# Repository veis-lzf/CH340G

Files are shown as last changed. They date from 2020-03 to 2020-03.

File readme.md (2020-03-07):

# CH340G下载器说明

- 如果需要使用免冷启动下载功能，在第一次使用时，需要用普通USB转TLL下载器给CH340G板上的STC15F104W下载固件（./Firmware/MDK5/Objects/CH340G-DL.hex）

	CH340G

- 烧录步骤说明：

	```
	1.连线： 
			USB转TTL下载器          CH340G自动下载器
	              TXD------------------->RX
	              RXD------------------->TX
	              
	2.给USB转TTL下载器上电，打开STC-ISP烧录工具;
	
	3.选择单片机型号为STC15F104W，选择COM口号，最低波特率为2400，程序运行频率为11.0592MHz；
	
	4.装载固件（/Firmware/MDK5/Objects/CH340G-DL.hex）；
	
	5.点击下载，给CH340G自动下载器上电（插上USB）；
	
	6.等待下载完毕，拔掉连线，完成。
	
	注：若烧写不成功，拔出CH340G自动下载器的USB，重复步骤5。
	```

- 若需要CH340G自动下载器给目标板供电，建议板载的三极管Q1更换为与s8550引脚兼容的大电流PNP管，如ss8550；如果不需要供电，则不需要焊接三极管Q1。

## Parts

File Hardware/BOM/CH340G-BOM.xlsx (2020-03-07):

Item | Reference | Value | PCB Footprint | Quantity
1 | C1 | 0.01uF | C0603 | 1
2 | C2 | 0.1uF | C0603 | 1
3 | C3 | 10uF | TA3216 | 1
4 | C4、C5 | 22pF | C0603 | 2
5 | C6 | 22uF | TA3216 | 1
6 | C7 | 0.1uF/NC | C0603 | 1
7 | D1 | 1N5819 | SOD123 | 1
8 | D2 | RED LED | LED0603 | 1
9 | D3 | YELLOW LED | LED0603 | 1
10 | D4 | GREEN LED | LED0603 | 1
11 | F1 | 1A | FULSE0805 | 1
12 | J1 | SMT-CON-4P-1R25 | 1_25_PWT_4P | 1
13 | J2 | CON4 | SIP-4 | 1
14 | J3 | CON2 | SIP-2 | 1
15 | Q1 | S8550 | SOT-23 | 1
16 | R1 | 300R | R0603 | 1
17 | R2、R3、R4、R5 | 1k | R0603 | 4
18 | USB1 | USB_A | USB-A-M-DIP | 1
19 | U1 | CH340G | SOIC-16 | 1
20 | U2 | STC15F104W | SOIC-8 | 1
21 | Y1 | 12MHz | HC-49S | 1

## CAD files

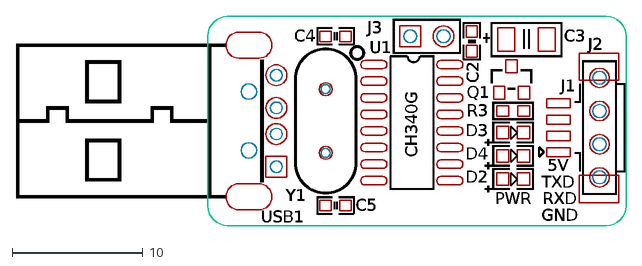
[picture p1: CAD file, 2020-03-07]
Hardware/PCB/Output/CH340G-PCB_TOP.dxf
J3
USB1
Y1
R3
D3
D4
D2
C2
C4
C5
C3
Q1
J2
J1
U1
PWR
CH340G
GND
TXD
RXD
5V

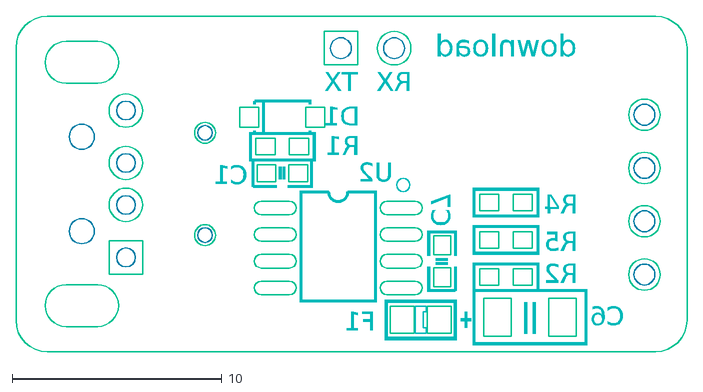
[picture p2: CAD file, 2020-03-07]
Hardware/PCB/Output/CH340G-PCB_BOTTOM.dxf
F1
R5
R4
R2
R1
C1
C7
D1
C6
U2
download
RX
TX

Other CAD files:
Firmware/MDK5/Objects/main.obj
Firmware/MDK5/Objects/STARTUP.obj

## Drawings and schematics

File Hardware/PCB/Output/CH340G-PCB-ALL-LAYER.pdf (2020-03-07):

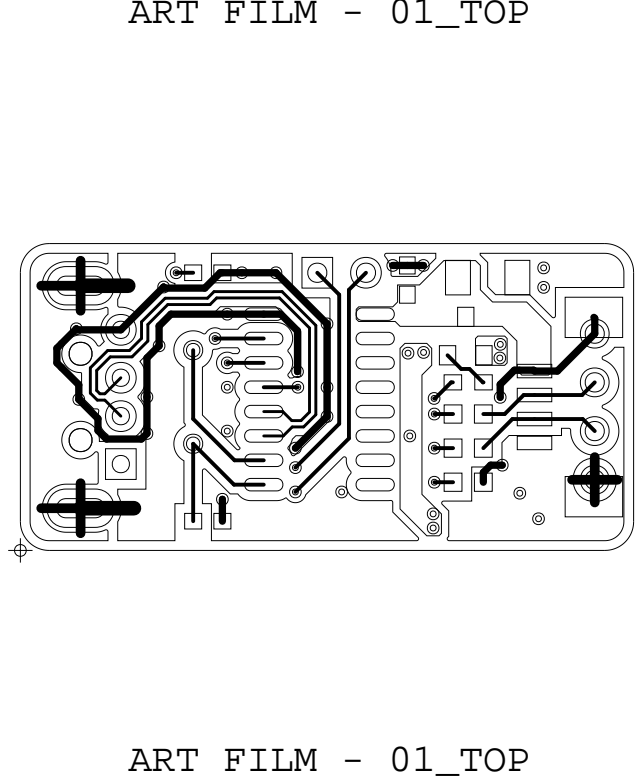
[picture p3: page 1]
ART FILM - 01_TOP

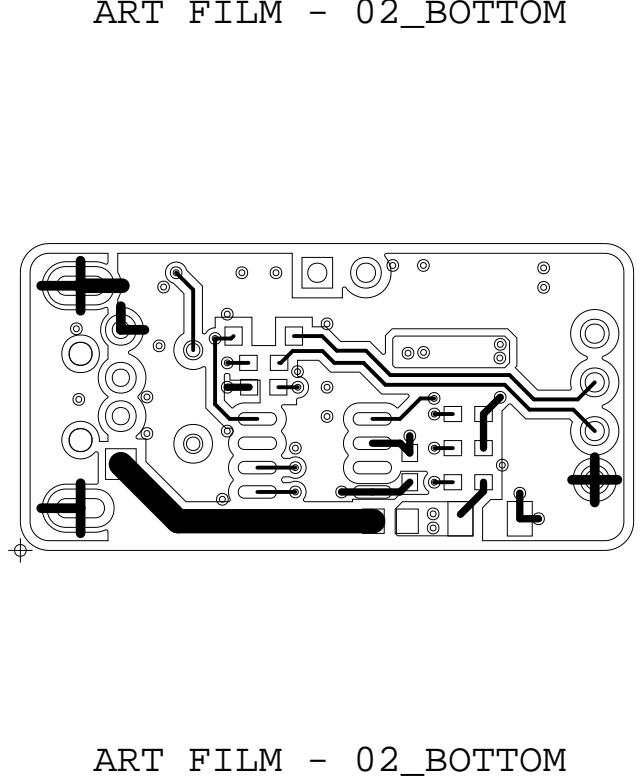
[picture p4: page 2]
ART FILM - 02_BOTTOM

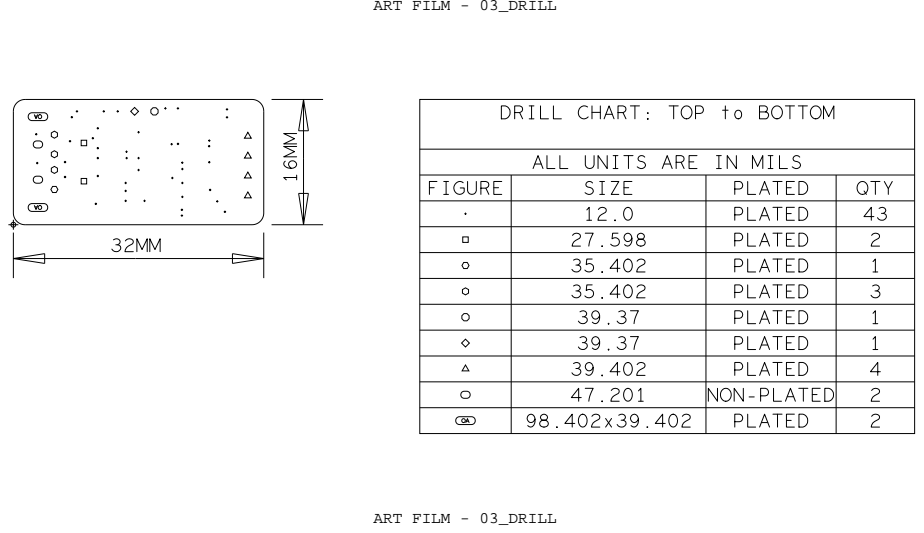
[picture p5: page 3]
ART FILM - 03_DRILL; QTY; PLATED; NON-PLATED; SIZE; ALL UNITS ARE IN MILS; DRILL CHART: TOP; to BOTTOM; FIGURE

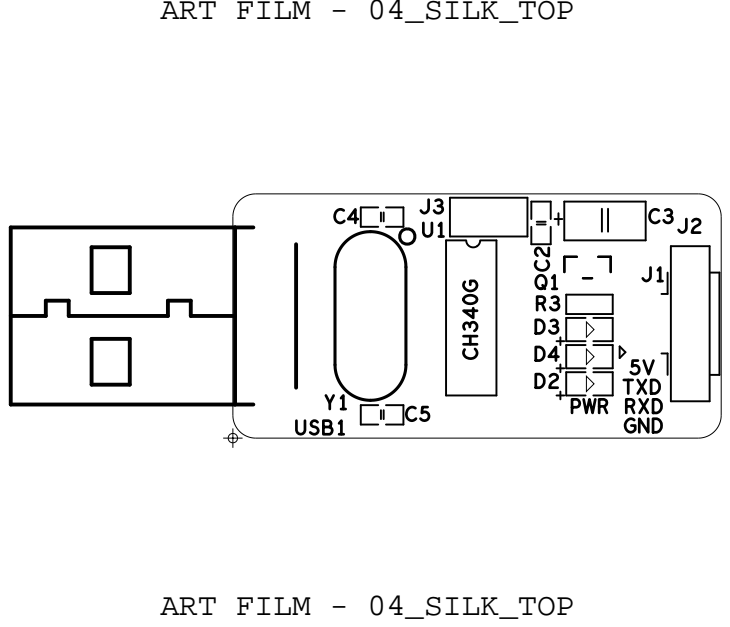
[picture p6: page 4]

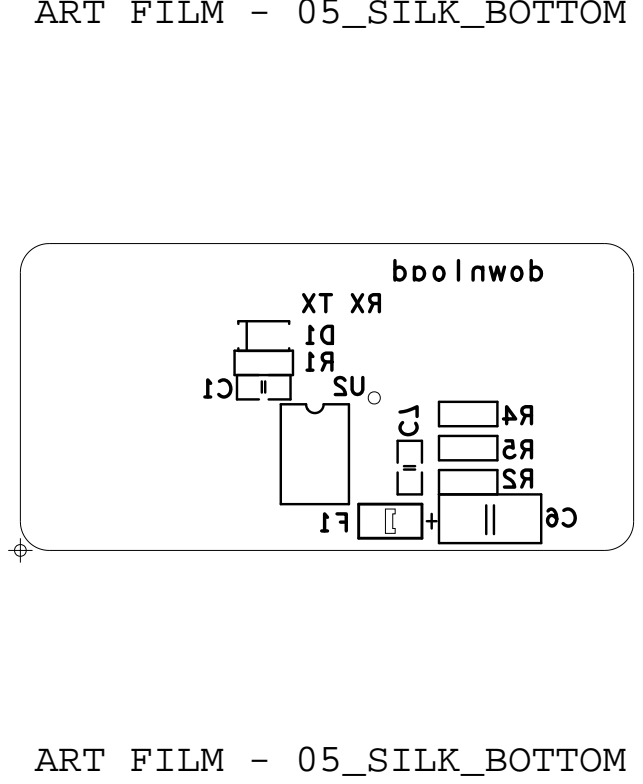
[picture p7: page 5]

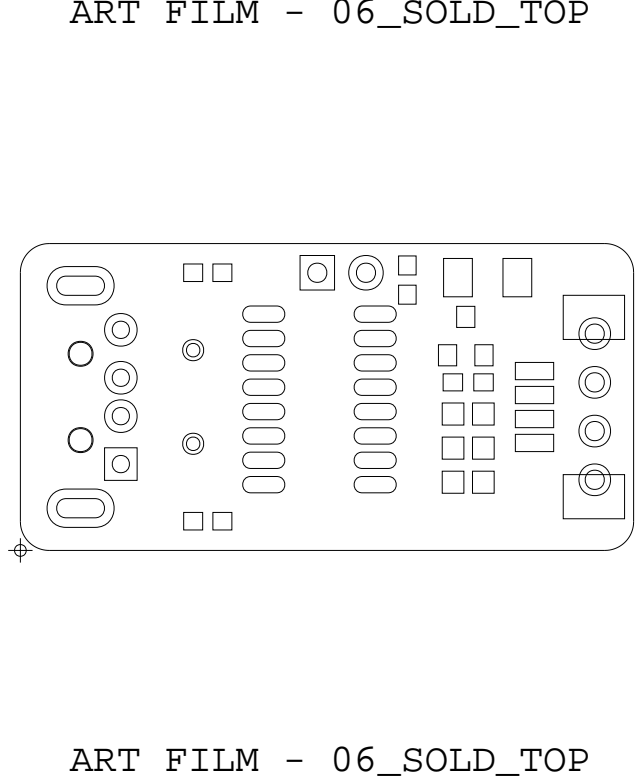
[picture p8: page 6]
ART FILM - 06_SOLD_TOP

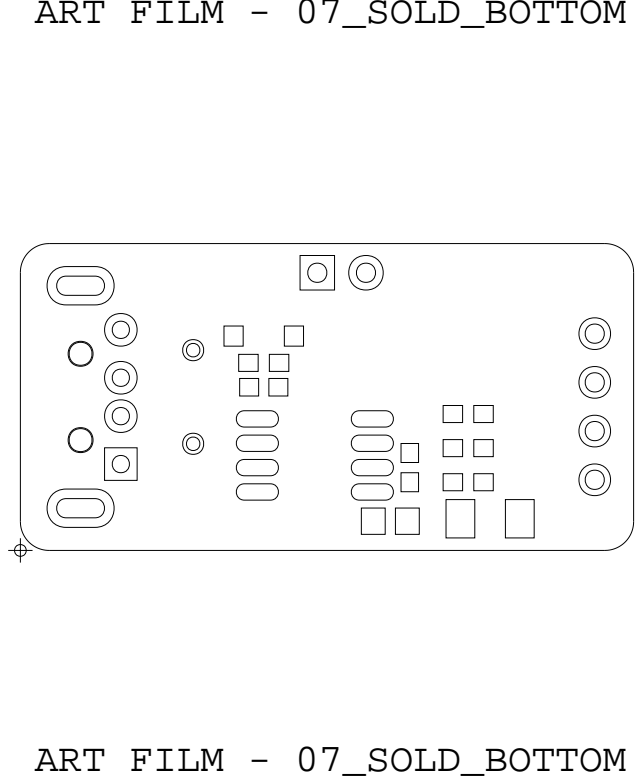
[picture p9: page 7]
ART FILM - 07_SOLD_BOTTOM

ART FILM - 08_PAST_TOP

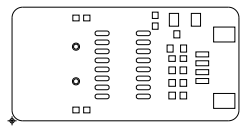
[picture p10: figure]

ART FILM - 08_PAST_TOP

ART FILM - 09_PAST_BOTTOM

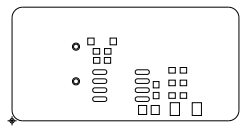
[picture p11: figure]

ART FILM - 09_PAST_BOTTOM

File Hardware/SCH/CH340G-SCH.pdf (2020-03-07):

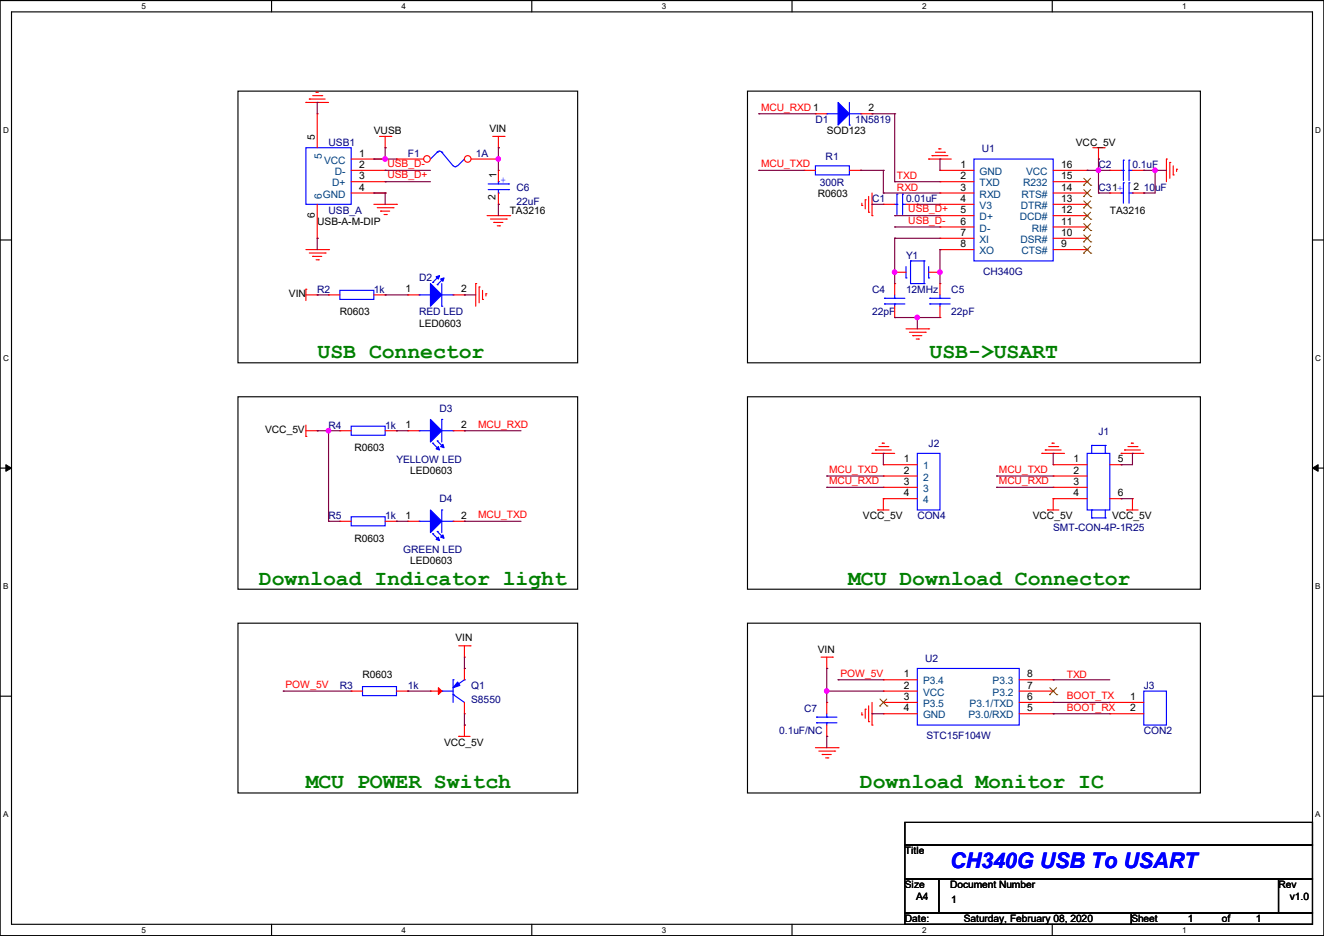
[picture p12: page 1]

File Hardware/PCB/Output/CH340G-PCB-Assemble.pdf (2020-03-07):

# ART FILM - ADT

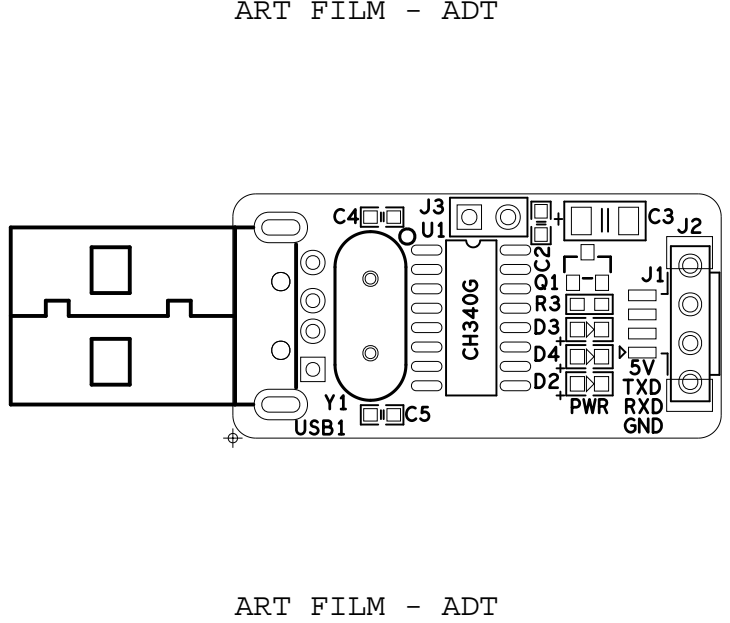
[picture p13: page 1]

# ART FILM - ADB

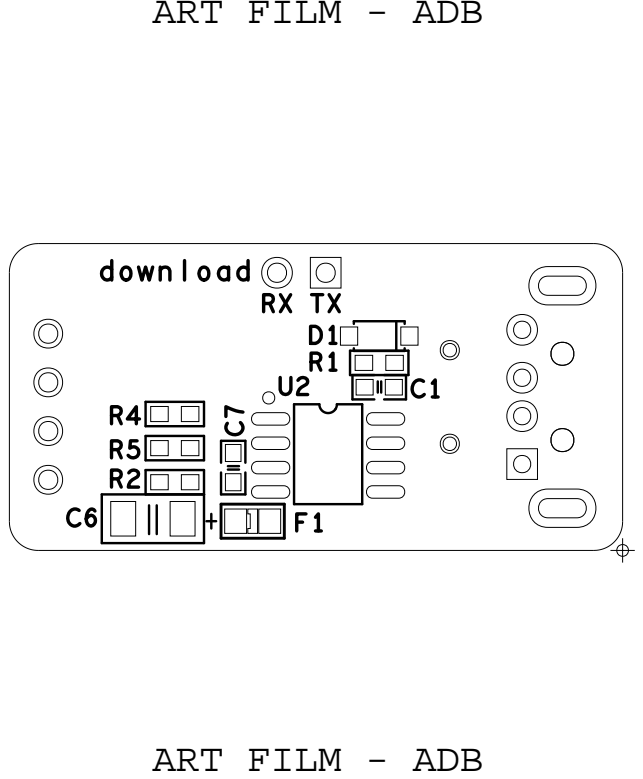
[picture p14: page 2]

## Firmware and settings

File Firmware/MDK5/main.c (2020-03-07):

/**
 *        STC单片机自动下载器
 *    MCU STC15F104W   11.0592MHZ
 **/

#include <reg52.h> // 52系列单片机特殊寄存器头文件
#define uint unsigned int // 宏定义
#define uchar unsigned char
	
/********单片机I/O功能声明*********/
sbit DYKZD=P3^4;// 电源控制端
sbit XZXHD=P3^3;// 下载信号检测端
uchar x;		// 下载信号低电平个数

/**************初始化**************/
void init() // 初始化子函数
{
	DYKZD=0; // 电源控制端打开
	XZXHD=1;
	INT1= 1;
	IT1 = 1; // 设置INT1的中断类型 (1:仅下降沿 0:上升沿和下降沿)
	EX1 = 1; // 使能INT1中断
	EA  = 1; // 打开总中断开关
}

/*************延时函数*************/
void delayms(uint xms) // 延时子函数
{
	uint i,j;
	for(i=xms;i>0;i--)
	for(j=110;j>0;j--);
}

/************外部中断ITN1********/
void exint1() interrupt 2       // INT1中断入口
{
	x++;
}

/**************主程序************/
void main() // 主程序
{
	init();
	while(1)
	{
		if(x>60)
		{
			DYKZD=1;
			delayms(500);
			DYKZD=0;
			delayms(60000);
			x=0;
		}
	}
}
